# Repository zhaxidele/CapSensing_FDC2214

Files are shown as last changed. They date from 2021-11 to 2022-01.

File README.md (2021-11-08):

# CapSensing_FDC2214
This a compact toolkit of capacitive sensing based on FDC2214 from Texas Instrument.

Sources including the hardware files of a capacitive sensing board with FDC2214, the driver files of FDC2214, the firmware code using Arduino BLE Nano as the mother board(of course suitable for other open source boards, even no need for any modification at all.)



Feel free to use and comment.

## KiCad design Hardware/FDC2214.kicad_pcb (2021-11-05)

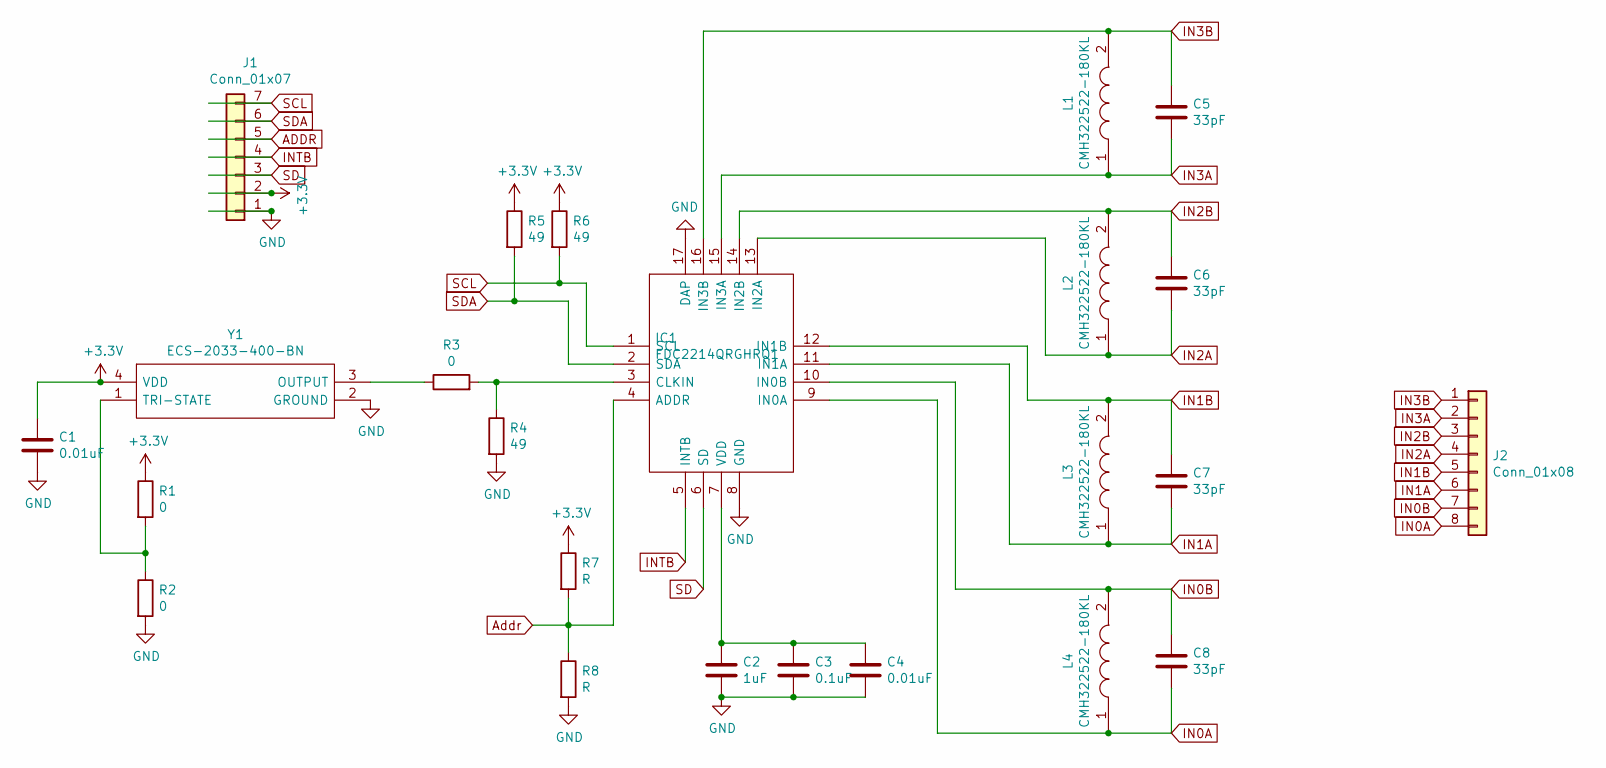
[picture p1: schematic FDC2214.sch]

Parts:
C1, C4: 0.01uF; C_0603_1608Metric
C2: 1uF; C_0603_1608Metric
C3: 0.1uF; C_0603_1608Metric
C5, C6, C7, C8: 33pF; C_0603_1608Metric
IC1: FDC2214QRGHRQ1; QFN50P400X400X80-17N; Manufacturer_Part_Number FDC2214QRGHRQ1; Mouser Part Number 595-FDC2214QRGHRQ1
J1: Conn_01x07; PinHeader_1x07_P2.54mm_Vertical
J2: Conn_01x08; PinHeader_1x08_P2.54mm_Vertical
L1, L2, L3, L4: CMH322522-180KL; INDPM3225X240N; Mouser Part Number 652-CMH322522-180KL
R1, R2, R3: 0; R_0603_1608Metric_Pad0.98x0.95mm_HandSolder
R4, R5, R6: 49; R_0603_1608Metric_Pad0.98x0.95mm_HandSolder
R7, R8: R; R_0603_1608Metric_Pad0.98x0.95mm_HandSolder
Y1: ECS-2033-400-BN; ECS2033400BN; Mouser Part Number 520-2033-400-BN

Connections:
+3V3: C1.1, J1.2, R1.1, R5.1, R6.1, R7.1, Y1.4 (VDD)
ADDR: J1.5
Addr: IC1.4 (ADDR), R7.2, R8.1
GND: C1.2, C2.2, C3.2, C4.2, IC1.8 (GND), IC1.17 (DAP), J1.1, R2.2, R4.2, R8.2, Y1.2 (GROUND)
IN0A: C8.2, IC1.9 (IN0A), J2.8, L4.1
IN0B: C8.1, IC1.10 (IN0B), J2.7, L4.2
IN1A: C7.2, IC1.11 (IN1A), J2.6, L3.1
IN1B: C7.1, IC1.12 (IN1B), J2.5, L3.2
IN2A: C6.2, IC1.13 (IN2A), J2.4, L2.1
IN2B: C6.1, IC1.14 (IN2B), J2.3, L2.2
IN3A: C5.2, IC1.15 (IN3A), J2.2, L1.1
IN3B: C5.1, IC1.16 (IN3B), J2.1, L1.2
INTB: IC1.5 (INTB), J1.4
unnamed: C2.1, C3.1, C4.1, IC1.7 (VDD)
unnamed: IC1.3 (CLKIN), R3.2, R4.1
unnamed: R1.2, R2.1, Y1.1 (TRI-STATE)
unnamed: R3.1, Y1.3 (OUTPUT)
SCL: IC1.1 (SCL), J1.7, R6.2
SD: IC1.6 (SD), J1.3
SDA: IC1.2 (SDA), J1.6, R5.2

Board: 2 copper layers, 24 parts (0 on the bottom side), 19 nets, no tracks yet.

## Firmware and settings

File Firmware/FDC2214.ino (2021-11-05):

#include <Wire.h>
#include "Cap_2214.h"

#define CHAN_COUNT 4

Cap_2214 Cap;
unsigned int num;


int led_State = LOW;
void blinkLED(void)
{
  if (led_State == LOW) {
    led_State = HIGH;
    digitalWrite(LED_BUILTIN, LOW);
  } else {
    led_State = LOW;
    digitalWrite(LED_BUILTIN, HIGH);
  }
}


void setup() {

  pinMode(LED_BUILTIN, OUTPUT);

    
  //SD,INTB,ADDR
  pinMode(6, OUTPUT);
  digitalWrite(6, LOW);
  pinMode(5, INPUT);
  pinMode(9, OUTPUT);
  digitalWrite(9, LOW);


  // ### Start I2C 
  Wire.begin();
  
  // ### Start serial
  Serial.begin(115200);
  
  delay(100); 
  
  //Start FDC, select the channels being used
  bool Cap_init = Cap.init(0xF);  
  if (Cap_init) Serial.println("FDC passed");  
  else Serial.println("FDC failed");  


}


void loop() {
  signed long capa[CHAN_COUNT]; // variable to store data from FDC
  //unsigned long Start = millis();
  for (int i = 0; i < CHAN_COUNT; i++){ // for each channel
    capa[i]= Cap.Read(i);//  
    Serial.print(capa[i]);  
    if (i < CHAN_COUNT-1) Serial.print(",");
    else Serial.println("");

  }

  num++;
  if (num == 10){
    blinkLED();
    num = 0;
  }

}

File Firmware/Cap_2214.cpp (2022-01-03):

// This is a driver file for FDC2214
// By szb, DFKI, 01.05.2021
// This file is based on related driver files by Chris Nelson, and Harijs Zablockis
//
// Addressed the double read issue.
//
// Feel free to use, modify, comment, and share.
//


#include "Arduino.h"
#include <Wire.h>
#include "Cap_2214.h"


// address
// uint8_t i2caddr;
//uint8_t i2caddr = 0x2B;

// Verify the chip
boolean Cap_2214::init(uint8_t CHs,  uint8_t Add, uint16_t Sample_Rate) {
    Wire.begin();
    i2caddr = Add;
    int ID = read_Cap(Cap_2214_DEVICE_ID);
    if (ID != 0x3055) {
        return false;
    }
    Channel_Select(CHs, Sample_Rate);
    return true;
}


//Internal routine to do actual chip init
void Cap_2214::Channel_Select(uint8_t Ch_Mask, uint16_t Sample_Rate) {

    //write_Cap(Cap_2214_CONFIG, 0x1601);  //internal Oscillator
    write_Cap(Cap_2214_CONFIG, 0x1E81);   // External Oscillator
	
    //select ch1:
	if (Ch_Mask & 0x01) {
        write_Cap(Cap_2214_SETTLECOUNT_CH0, 0x012C);     // 25.05.2021 300
		//write_Cap(Cap_2214_RCOUNT_CH0, 0xFFFF);
        //0x2FFF: around 50Hz(four channel)   0xFFFF: around 10Hz(four channel)  0x4FFF: around 30Hz(four channel)
        write_Cap(Cap_2214_RCOUNT_CH0, 0x4FFF);   // drop reslution, increase conversion speed
		write_Cap(Cap_2214_OFFSET_CH0, 0x0000);
        write_Cap(Cap_2214_CLOCK_DIVIDERS_CH0, 0x2001);   // 25.05.2021  0.01 to 10 MHz, single mode
        //write_Cap(FDC2214_CLOCK_DIVIDERS_CH0, 0x1001);   // 25.05.2021  0.01 to 8.75MHz, double mode
		write_Cap(Cap_2214_DRIVE_CH0, 0xF800);
	}
	// select ch2:
	if (Ch_Mask & 0x02) {
		write_Cap(Cap_2214_SETTLECOUNT_CH1, 0x012C);
		//write_Cap(Cap_2214_RCOUNT_CH1, 0xFFFF);
        write_Cap(Cap_2214_RCOUNT_CH1, 0x4FFF);   // drop reslution, increase conversion speed
		write_Cap(Cap_2214_OFFSET_CH1, 0x0000);
		write_Cap(Cap_2214_CLOCK_DIVIDERS_CH1, 0x2001);
		write_Cap(Cap_2214_DRIVE_CH1, 0xF800);
	}
    // select ch3:
	if (Ch_Mask & 0x04) {
		write_Cap(Cap_2214_SETTLECOUNT_CH2, 0x012C);
		//write_Cap(Cap_2214_RCOUNT_CH2, 0xFFFF);
        write_Cap(Cap_2214_RCOUNT_CH2, 0x4FFF);   // drop reslution, increase conversion speed
		write_Cap(Cap_2214_OFFSET_CH2, 0x0000);
		write_Cap(Cap_2214_CLOCK_DIVIDERS_CH2, 0x2001);
		write_Cap(Cap_2214_DRIVE_CH2, 0xF800);
	}
    // select ch4:
	if (Ch_Mask & 0x08) {
		write_Cap(Cap_2214_SETTLECOUNT_CH3, 0x012C);
		//write_Cap(Cap_2214_RCOUNT_CH3, 0xFFFF);
        write_Cap(Cap_2214_RCOUNT_CH3, 0x4FFF);   // drop reslution, increase conversion speed
		write_Cap(Cap_2214_OFFSET_CH3, 0x0000);
		write_Cap(Cap_2214_CLOCK_DIVIDERS_CH3, 0x2001);
		write_Cap(Cap_2214_DRIVE_CH3, 0xF800);
	}	

    uint8_t RR_Se = 0x06;
    uint8_t glitchfilter = 0x05;
	uint16_t mux = 0x0208 | ((uint16_t)RR_Se << 13) | glitchfilter;
    write_Cap(Cap_2214_MUX_CONFIG, mux);
    
}


unsigned long Cap_2214::Read(uint8_t Ch) {

    unsigned long result = 0;
    uint8_t add_MSB;
	uint8_t add_LSB;
	uint8_t UnreadConv;
	switch (Ch){
		case (0):
			add_MSB = Cap_2214_DATA_CH0_MSB;
			add_LSB = Cap_2214_DATA_CH0_LSB;
			UnreadConv = 0x0008;
		break;
		case (1):
			add_MSB = Cap_2214_DATA_CH1_MSB;
			add_LSB = Cap_2214_DATA_CH1_LSB;
			UnreadConv = 0x0004;
		break;
		case (2):
			add_MSB = Cap_2214_DATA_CH2_MSB;
			add_LSB = Cap_2214_DATA_CH2_LSB;
			UnreadConv = 0x0002;
		break;
		case (3):
			add_MSB = Cap_2214_DATA_CH3_MSB;
			add_LSB = Cap_2214_DATA_CH3_LSB;
			UnreadConv = 0x0001;
		break;
		default: return 0;
	}
	
    int status = read_Cap(Cap_2214_STATUS);
    while (!(status & UnreadConv)) {
        status = read_Cap(Cap_2214_STATUS);
    }
    result = (uint32_t)(read_Cap(add_MSB) & 0x0FFF) << 16;
    result |= read_Cap(add_LSB);
    return result;
}


// Read 2 bytes
uint16_t Cap_2214::read_Cap(uint16_t address) {
    uint16_t data;
    Wire.beginTransmission(i2caddr);
    Wire.write(address);
    Wire.endTransmission(false);
    Wire.requestFrom(i2caddr, (uint8_t) 2);
    while (!Wire.available());
    data = Wire.read();
    data <<= 8;
    while (!Wire.available());
    data |= Wire.read();
    Wire.endTransmission(true);
    return data;
}


// write 2 bytes
void Cap_2214::write_Cap(uint16_t address, uint16_t data) {
    Wire.beginTransmission(i2caddr);
    Wire.write(address & 0xFF);
    Wire.write(data >> 8);
    Wire.write(data);
    Wire.endTransmission();
}
